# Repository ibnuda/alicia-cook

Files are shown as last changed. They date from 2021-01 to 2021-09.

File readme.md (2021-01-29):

# alicia cook

yet another uninspiring, boring, and beaten to death clone of alice "ergonomic"
keyboard. lol.

but, you should actually split it off and connect them using idc 2x5, tho.

## pics

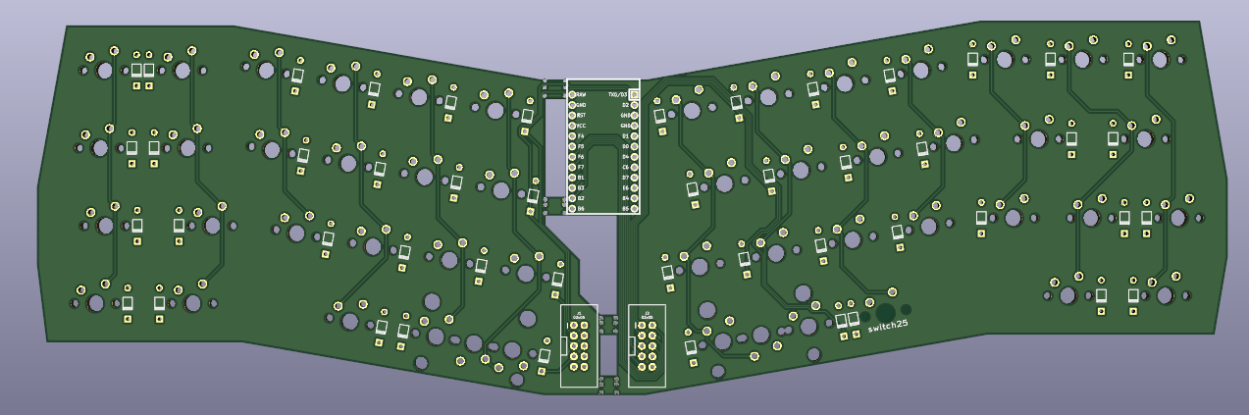
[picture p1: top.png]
top


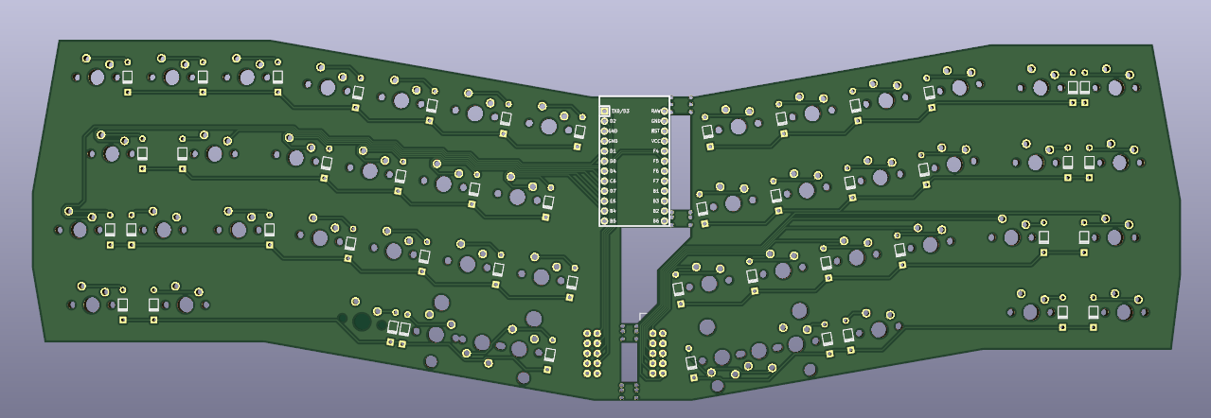
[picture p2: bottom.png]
bottom


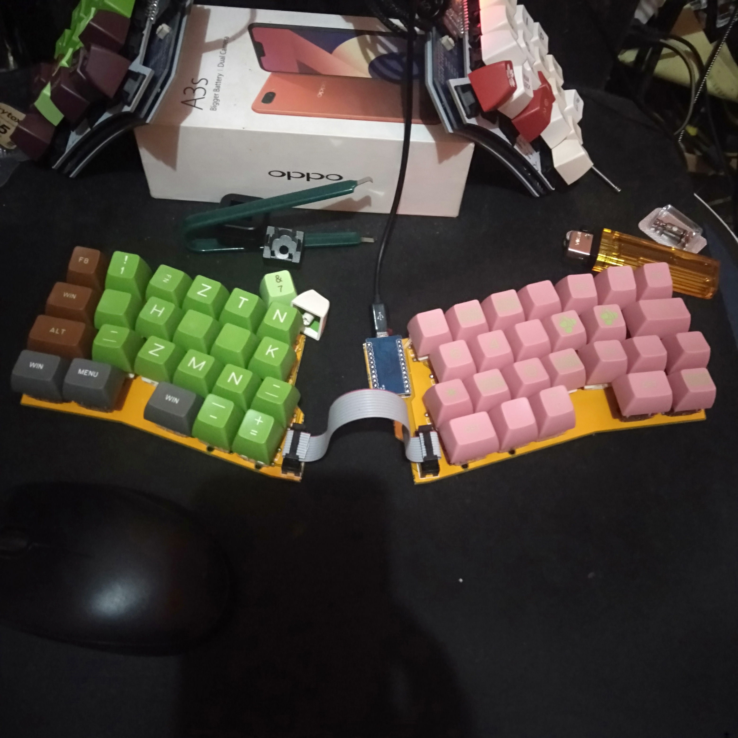
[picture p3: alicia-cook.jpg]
working condition


## license
of course it's GPLv3.

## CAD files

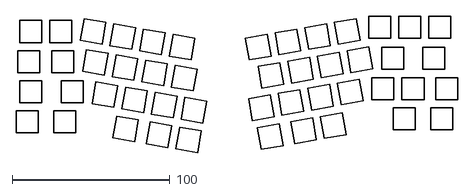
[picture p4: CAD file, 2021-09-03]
switch-hole.dxf
279.7 x 86.4

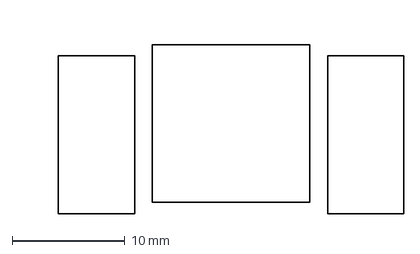
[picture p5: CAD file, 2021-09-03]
2u.dxf
34.4 x 17.5 mm

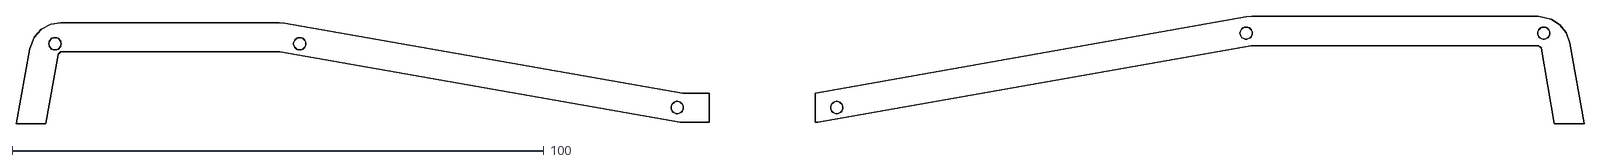
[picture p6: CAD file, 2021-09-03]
north_wall.dxf
294.9 x 20.1

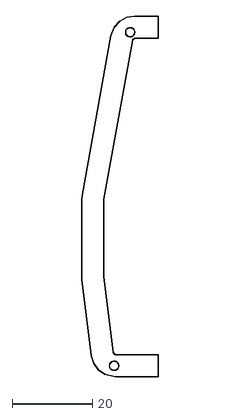
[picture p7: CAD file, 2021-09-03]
west_wall.dxf
19.1 x 89.7

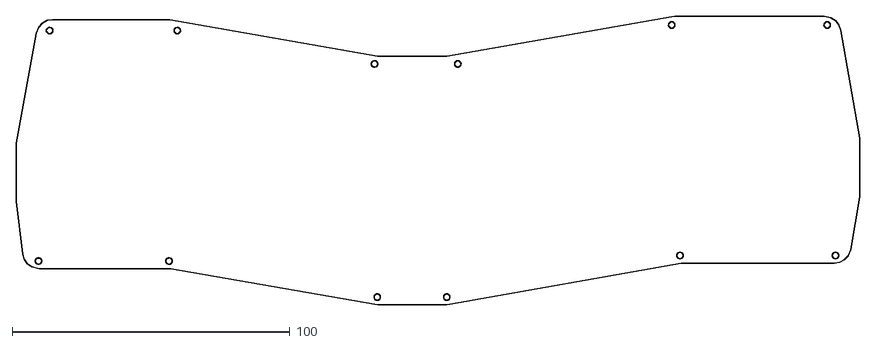
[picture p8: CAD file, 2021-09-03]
sandwich_bottom.dxf
303.8 x 103.8

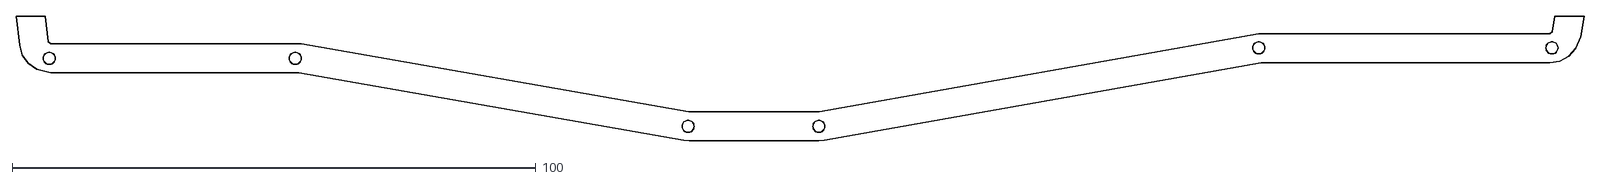
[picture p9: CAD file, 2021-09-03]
south_wall.dxf
299.5 x 23.7

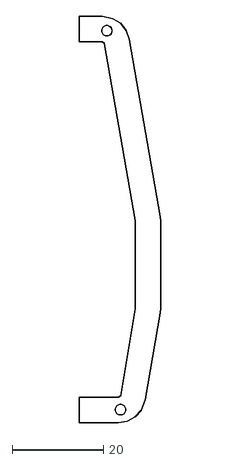
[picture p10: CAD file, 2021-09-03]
east_wall.dxf
17.8 x 89.0

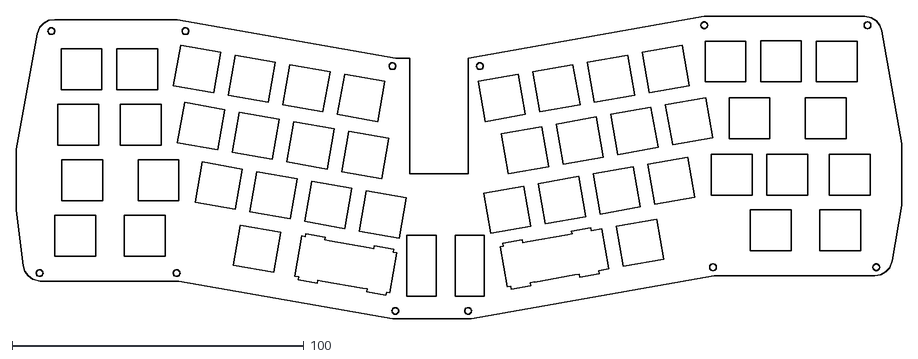
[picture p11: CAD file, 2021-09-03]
sandwich_plate.dxf
303.8 x 103.8

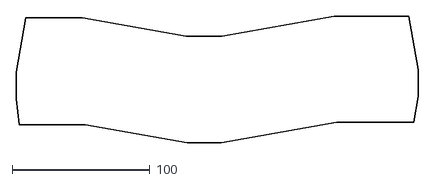
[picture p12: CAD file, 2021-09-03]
plate.dxf
291.8 x 91.8

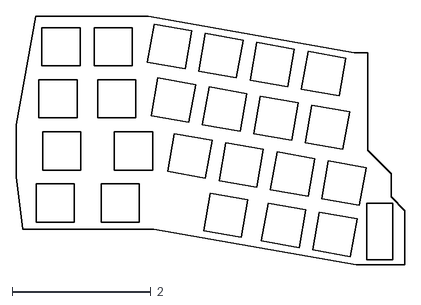
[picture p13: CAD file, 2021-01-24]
left-plate.dxf
5.59 x 3.57

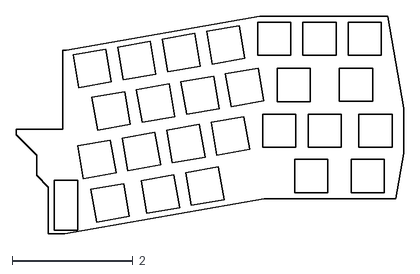
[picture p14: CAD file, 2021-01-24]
right-plate.dxf
6.43 x 3.62

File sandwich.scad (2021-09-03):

//
screw_placements = [
    [ 6, -15 ],
    [ 52, -15 ],
    [ 123, -27 ],
    [ 153, -27 ],
    [ 230, -13 ],
    [ 286, -13 ],

    [ 289, -96 ],
    [ 233, -96 ],
    [ 149, -111 ],
    [ 124, -111 ],
    [ 49, -98 ],
    [ 2, -98 ],
];

module
screw_hole()
{
    circle(r = 1.15, $fn = 30);
}

module
plate()
{
    offset(6) import("plate.dxf");
}

module pcb()
{
  offset(0.5) import("plate.dxf");
}

module
switch_hole()
{
    import("switch-hole.dxf");
}

module
promicro_and_socket_placement()
{
    union()
    {
        polygon(points = [
            [ 129, 0 ],
            [ 129, -64 ],
            [ 149, -64 ],
            [ 149, 0 ],
        ]);
        polygon(points = [
            [ 128, -85 ],
            [ 128, -106 ],
            [ 138, -106 ],
            [ 138, -85 ],
        ]);
        polygon(points = [
            [ 144.5, -85 ],
            [ 144.5, -106 ],
            [ 154.5, -106 ],
            [ 154.5, -85 ],
        ]);
    }
}

module
sandwich_bottom()
{
    difference()
    {
        plate();
        for (i = [0:len(screw_placements) - 1]) {
            translate(screw_placements[i]) screw_hole();
        }
    }
}

module 2u()
{
    union()
    {
        translate([ -19, 9.5 ]) import("2u.dxf");
        rotate([ 0, 0, 180 ]) translate([ -19, 9.5 ]) import("2u.dxf");
    }
}

module 2us()
{
    union()
    {
        translate([ 107.0746, -95.03 ]) rotate([ 0, 0, -10 ]) 2u();
        translate([ 177.4591, -92.965 ]) rotate([ 0, 0, 10 ]) 2u();
    }
}

module
sandwich_plate()
{
    difference()
    {
        plate();
        switch_hole();
        for (i = [0:len(screw_placements) - 1]) {
            translate(screw_placements[i]) screw_hole();
        }
        promicro_and_socket_placement();
        2us();
    }
}

module
wall()
{
  difference()
  {
    plate();
    pcb();
    promicro_and_socket_placement();
        for (i = [0:len(screw_placements) - 1]) {
            translate(screw_placements[i]) screw_hole();
        }
  }
}

module
north_wall()
{
  difference()
  {
    wall();
    translate([0, -80, 0]) square(size=[600, 100], center=true);
  }
}

module west_wall()
{
    difference()
    {
        wall();
        translate([13, -120, 0]) square(size=[400, 400], center=false);
    }
}

module south_wall()
{
  difference()
  {
    wall();
    translate([0, -40, 0]) square(size=[600, 100], center=true);
  }
}

module east_wall()
{
    difference()
    {
        wall();
        translate([-120, -120, 0]) square(size=[400, 400], center=false);
    }
}
east_wall();

// sandwich_bottom();
// translate([ 0, 95, 0 ]) sandwich_plate();
// sandwich_plate();

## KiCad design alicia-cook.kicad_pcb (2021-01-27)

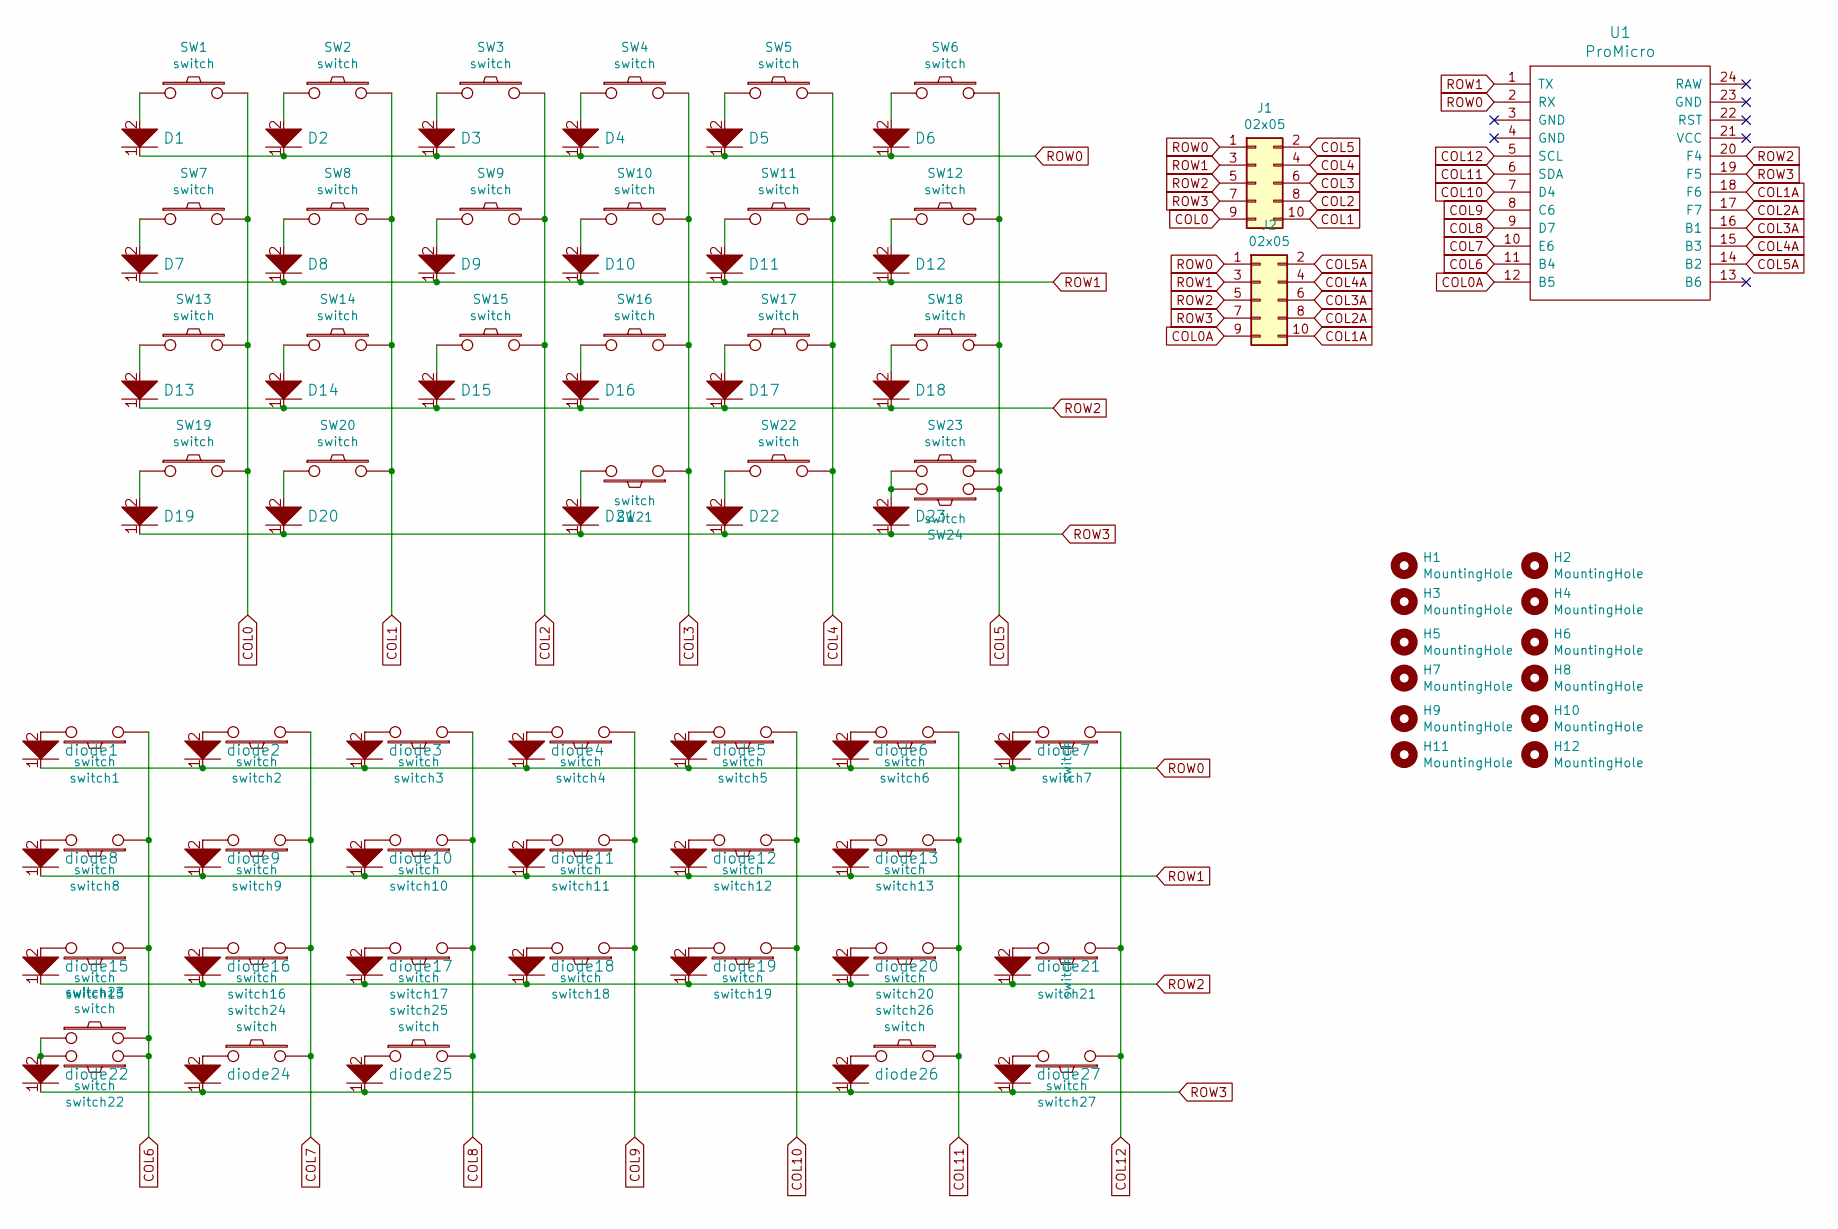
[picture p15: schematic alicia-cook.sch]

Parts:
D1, D2, D3, D4, D5, D6, D7, D8, D9, D10, D11, D12, D13, D14, D15, D16, D17, D18, D19, D20, D21, D22, D23: D; diode
H1, H3: MountingHole; hole-three-bigger
H2, H4, H5, H6, H7, H8, H9, H10, H11, H12: MountingHole; hole-three
J1, J2: 02x05; connector-shrouded
SW1, SW2, SW3, SW4, SW5, SW6, SW8, SW9, SW10, SW11, SW12, SW14, SW15, SW16, SW17, SW18, SW22, SW23: switch; 1u-minimal
SW7, SW19, SW20, SW21: switch; 125u-minimal
SW13: switch; 175u-minimal
SW24: switch; 2u-minimal
U1: ProMicro; promicro
diode1, diode2, diode3, diode4, diode5, diode6, diode7, diode8, diode9, diode10, diode11, diode12, diode13, diode15, diode16, diode17, diode18, diode19, diode20, diode21, diode22, diode24, diode25, diode26, diode27: diode
switch1, switch2, switch3, switch4, switch5, switch6, switch7, switch8, switch9, switch10, switch11, switch12, switch15, switch16, switch17, switch18, switch19, switch20, switch24, switch25: switch; 1u-minimal
switch13: switch; 175u-minimal
switch21, switch22, switch26, switch27: switch; 125u-minimal
switch23: switch; 225u-minimal

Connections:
COL0: J1.9, SW1.2, SW7.2, SW13.2, SW19.2
COL0A: J2.9, U1.12 (B5)
COL1: J1.10, SW2.2, SW8.2, SW14.2, SW20.2
COL1A: J2.10, U1.18 (F6)
COL2: J1.8, SW3.2, SW9.2, SW15.2
COL2A: J2.8, U1.17 (F7)
COL3: J1.6, SW4.2, SW10.2, SW16.2, SW21.1
COL3A: J2.6, U1.16 (B1)
COL4: J1.4, SW5.2, SW11.2, SW17.2, SW22.2
COL4A: J2.4, U1.15 (B3)
COL5: J1.2, SW6.2, SW12.2, SW18.2, SW23.2, SW24.1
COL5A: J2.2, U1.14 (B2)
COL6: U1.11 (B4), switch1.1, switch8.1, switch15.1, switch22.1, switch23.2
COL7: U1.10 (E6), switch2.1, switch9.1, switch16.1, switch24.2
COL8: U1.9 (D7), switch3.1, switch10.1, switch17.1, switch25.2
COL9: U1.8 (C6), switch4.1, switch11.1, switch18.1
COL10: U1.7 (D4), switch5.1, switch12.1, switch19.1
COL11: U1.6 (SDA), switch6.1, switch13.1, switch20.1, switch26.2
COL12: U1.5 (SCL), switch7.1, switch21.1, switch27.1
unnamed: D1.2, SW1.1
unnamed: D2.2, SW2.1
unnamed: D3.2, SW3.1
unnamed: D4.2, SW4.1
unnamed: D5.2, SW5.1
unnamed: D6.2, SW6.1
unnamed: D7.2, SW7.1
unnamed: D8.2, SW8.1
unnamed: D9.2, SW9.1
unnamed: D10.2, SW10.1
unnamed: D11.2, SW11.1
unnamed: D12.2, SW12.1
unnamed: D13.2, SW13.1
unnamed: D14.2, SW14.1
unnamed: D15.2, SW15.1
unnamed: D16.2, SW16.1
unnamed: D17.2, SW17.1
unnamed: D18.2, SW18.1
unnamed: D19.2, SW19.1
unnamed: D20.2, SW20.1
unnamed: D21.2, SW21.2
unnamed: D22.2, SW22.1
unnamed: D23.2, SW23.1, SW24.2
unnamed: diode1.2, switch1.2
unnamed: diode2.2, switch2.2
unnamed: diode3.2, switch3.2
unnamed: diode4.2, switch4.2
unnamed: diode5.2, switch5.2
unnamed: diode6.2, switch6.2
unnamed: diode7.2, switch7.2
unnamed: diode8.2, switch8.2
unnamed: diode9.2, switch9.2
unnamed: diode10.2, switch10.2
unnamed: diode11.2, switch11.2
unnamed: diode12.2, switch12.2
unnamed: diode13.2, switch13.2
unnamed: diode15.2, switch15.2
unnamed: diode16.2, switch16.2
unnamed: diode17.2, switch17.2
unnamed: diode18.2, switch18.2
unnamed: diode19.2, switch19.2
unnamed: diode20.2, switch20.2
unnamed: diode21.2, switch21.2
unnamed: diode22.2, switch22.2, switch23.1
unnamed: diode24.2, switch24.1
unnamed: diode25.2, switch25.1
unnamed: diode26.2, switch26.1
unnamed: diode27.2, switch27.2
ROW0: D1.1, D2.1, D3.1, D4.1, D5.1, D6.1, J1.1, J2.1, U1.2 (RX), diode1.1, diode2.1, diode3.1, diode4.1, diode5.1, diode6.1, diode7.1
ROW1: D7.1, D8.1, D9.1, D10.1, D11.1, D12.1, J1.3, J2.3, U1.1 (TX), diode8.1, diode9.1, diode10.1, diode11.1, diode12.1, diode13.1
ROW2: D13.1, D14.1, D15.1, D16.1, D17.1, D18.1, J1.5, J2.5, U1.20 (F4), diode15.1, diode16.1, diode17.1, diode18.1, diode19.1, diode20.1, diode21.1
ROW3: D19.1, D20.1, D21.1, D22.1, D23.1, J1.7, J2.7, U1.19 (F5), diode22.1, diode24.1, diode25.1, diode26.1, diode27.1

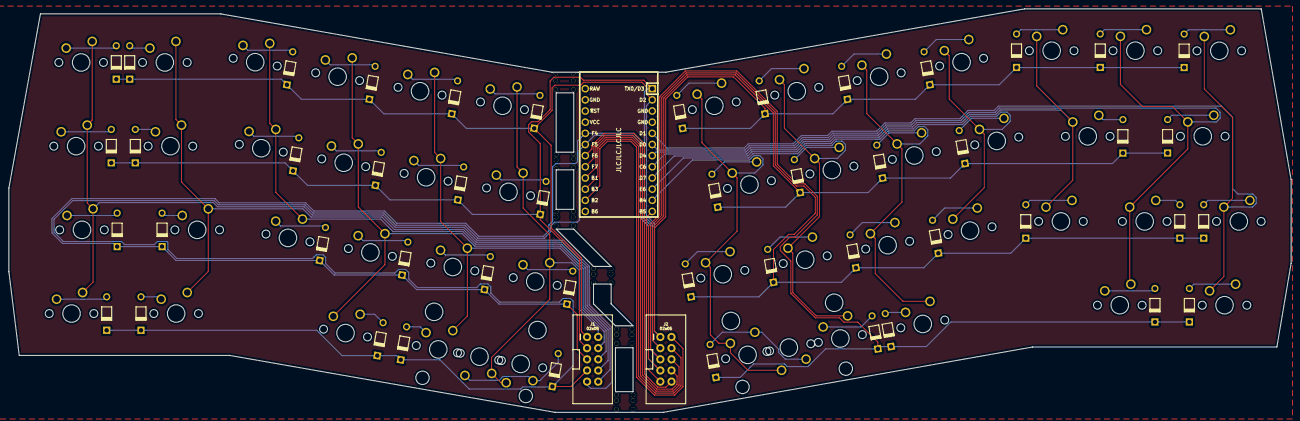
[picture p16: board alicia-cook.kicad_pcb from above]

Board: 2 copper layers, 291.8 x 91.8 mm, 113 parts (1 on the bottom side), 71 nets.

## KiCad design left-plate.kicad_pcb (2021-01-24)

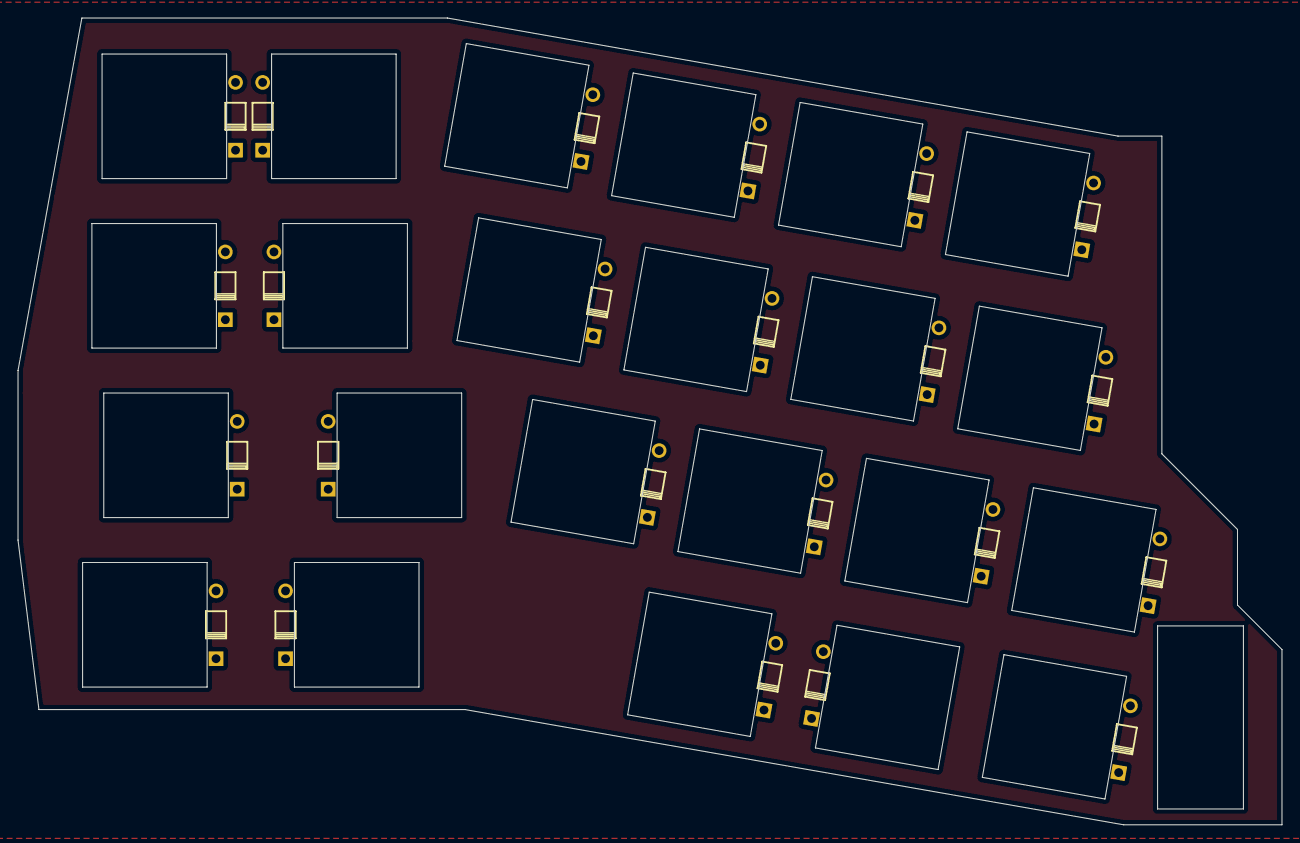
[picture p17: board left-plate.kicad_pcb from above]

Board: 2 copper layers, 142.1 x 90.7 mm, 46 parts (0 on the bottom side), 4 nets, no tracks yet.

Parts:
D1, D2, D3, D4, D5, D6, D7, D8, D9, D10, D11, D12, D13, D14, D15, D16, D17, D18, D19, D20, D21, D22, D23: D; diode
SW1, SW2, SW3, SW4, SW5, SW6, SW7, SW8, SW9, SW10, SW11, SW12, SW13, SW14, SW15, SW16, SW17, SW18, SW19, SW20, SW21, SW22, SW23: switch; hole-switch

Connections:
ROW0: D1.1, D2.1, D3.1, D4.1, D5.1, D6.1
ROW1: D7.1, D8.1, D9.1, D10.1, D11.1, D12.1
ROW2: D13.1, D14.1, D15.1, D16.1, D17.1, D18.1
ROW3: D19.1, D20.1, D21.1, D22.1, D23.1

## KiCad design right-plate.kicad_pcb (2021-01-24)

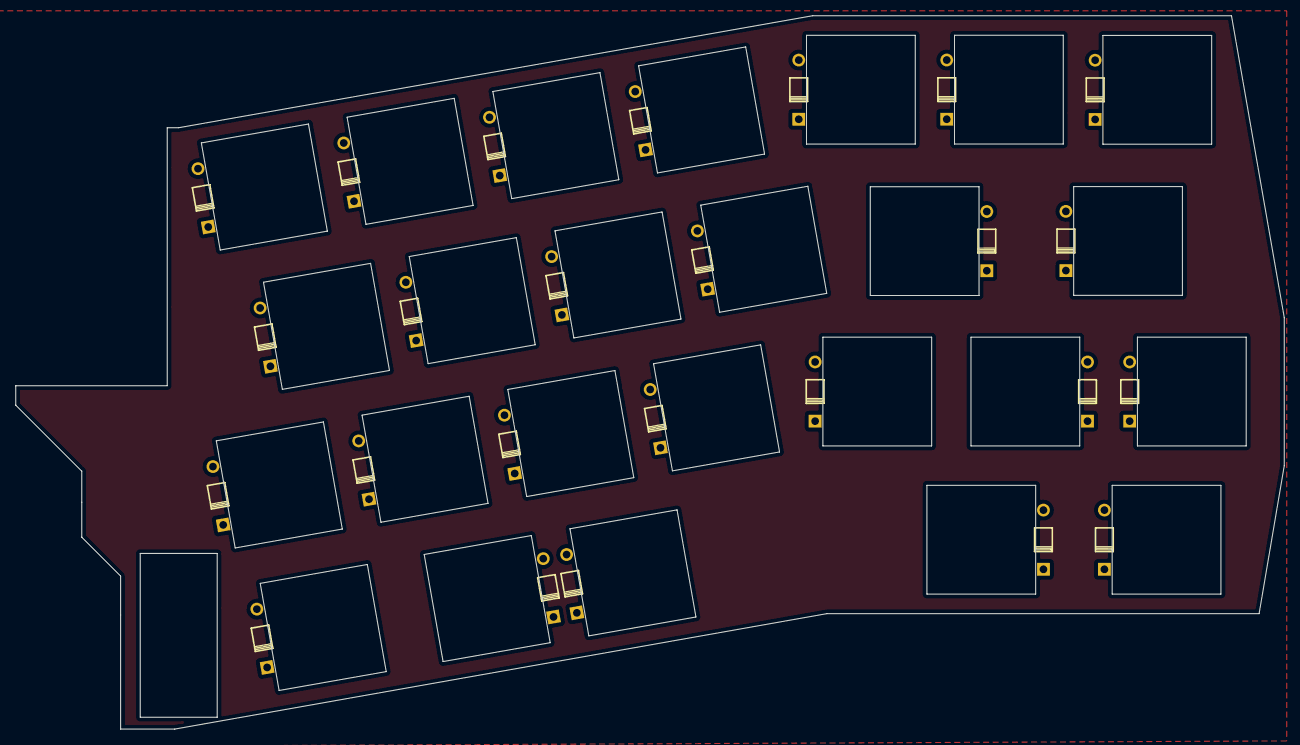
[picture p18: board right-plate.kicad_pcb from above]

Board: 2 copper layers, 163.3 x 91.8 mm, 50 parts (0 on the bottom side), 4 nets, no tracks yet.

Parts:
diode1, diode2, diode3, diode4, diode5, diode6, diode7, diode8, diode9, diode10, diode11, diode12, diode13, diode15, diode16, diode17, diode18, diode19, diode20, diode21, diode22, diode24, diode25, diode26, diode27: diode
switch1, switch2, switch3, switch4, switch5, switch6, switch7, switch8, switch9, switch10, switch11, switch12, switch13, switch15, switch16, switch17, switch18, switch19, switch20, switch21, switch22, switch24, switch25, switch26, switch27: switch; hole-switch

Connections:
ROW0: diode1.1, diode2.1, diode3.1, diode4.1, diode5.1, diode6.1, diode7.1
ROW1: diode8.1, diode9.1, diode10.1, diode11.1, diode12.1, diode13.1
ROW2: diode15.1, diode16.1, diode17.1, diode18.1, diode19.1, diode20.1, diode21.1
ROW3: diode22.1, diode24.1, diode25.1, diode26.1, diode27.1

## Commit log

2021-01-19 init commit.
    [alicia-cook.kicad_pcb, alicia-cook.sch]
2021-01-19 some wilding tracks smh my head.
    [alicia-cook.kicad_pcb]
2021-01-20 some route fixes.
    [alicia-cook.kicad_pcb, alicia-cook.sch]
2021-01-20 3d models.
    [alicia-cook.kicad_pcb]
2021-01-24 left and right switch plate.
    [alicia-cook.kicad_pcb, left-plate.dxf, left-plate.kicad_pcb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]
2021-09-03 sandwich plates.
    [2u.dxf, east_wall.dxf, north_wall.dxf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]
